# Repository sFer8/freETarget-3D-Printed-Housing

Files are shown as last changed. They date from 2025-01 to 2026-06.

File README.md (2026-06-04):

# freEtarget 3D Printed Housing

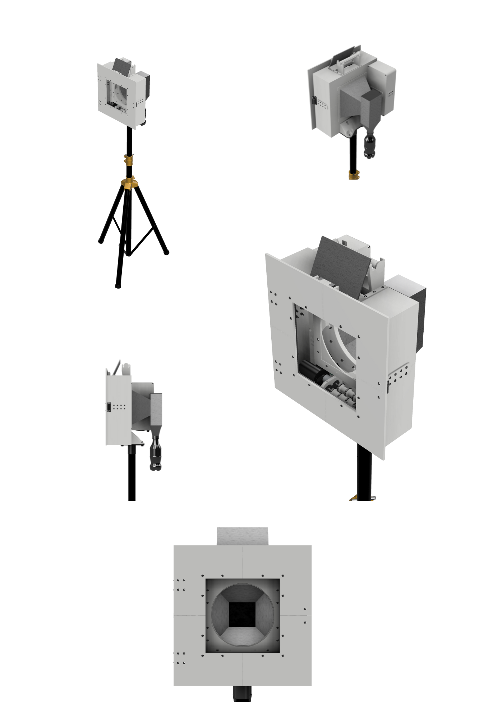
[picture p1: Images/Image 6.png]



## Warning

Some parts of the design have not been tested due to current funding limitations. For instance, my personal target does not include any metal protective components. Additionally, the released designs for the target's face have not been tested due to a shortage of filament. Holes to be printed may require the use of a drill to achieve the appropriate size.

### Paper Target and Witness Paper

The default paper target holder uses a standard 17x17cm target. Both rifle and pistol paper targets should use this size. SUIS style targets have another holder that can be printed however I have not had the chance to test it out. Custom target holders can be requested, but please provide important measurements to assist in their implementation.

For witness paper, a standard roll of black craft paper can be cut to 90mm wide and rolled onto the 3d printed roll holder. When using craft paper, it tends to bend behind the target. As such it will be necessary to put the witness paper in between two target papers as shown in order to have a more favorable result in scoring.

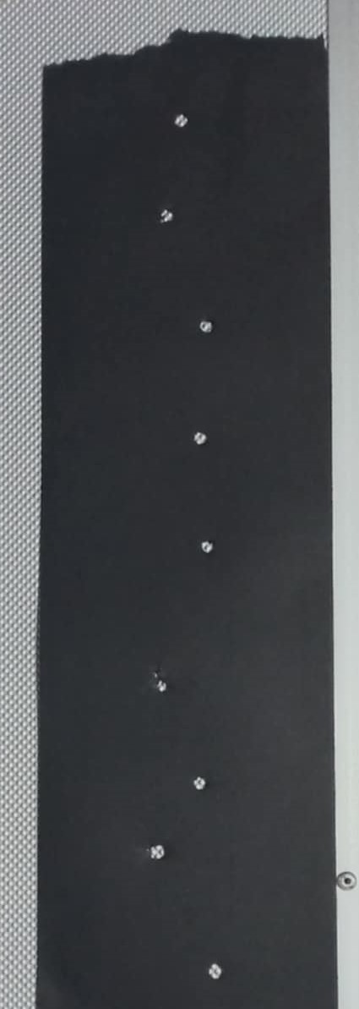
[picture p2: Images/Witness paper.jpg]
Witness paper

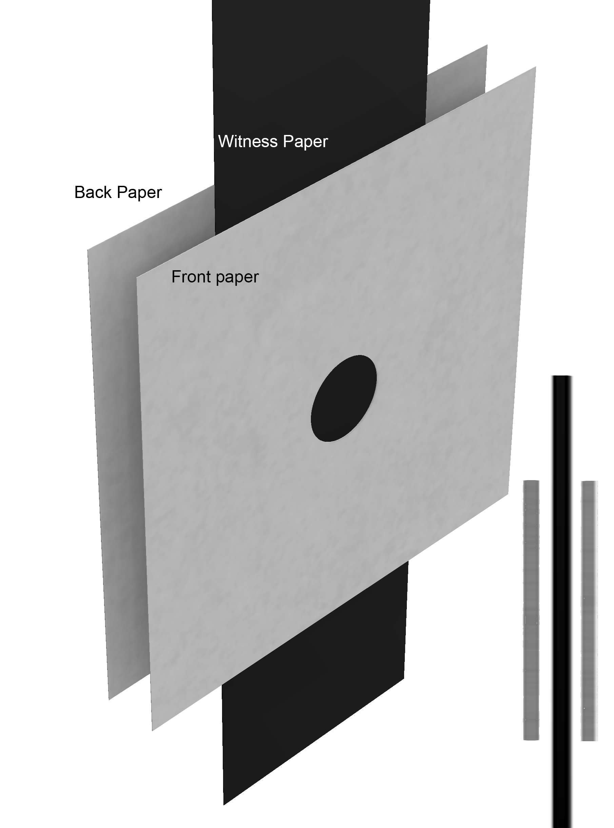
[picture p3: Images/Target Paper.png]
Target Paper

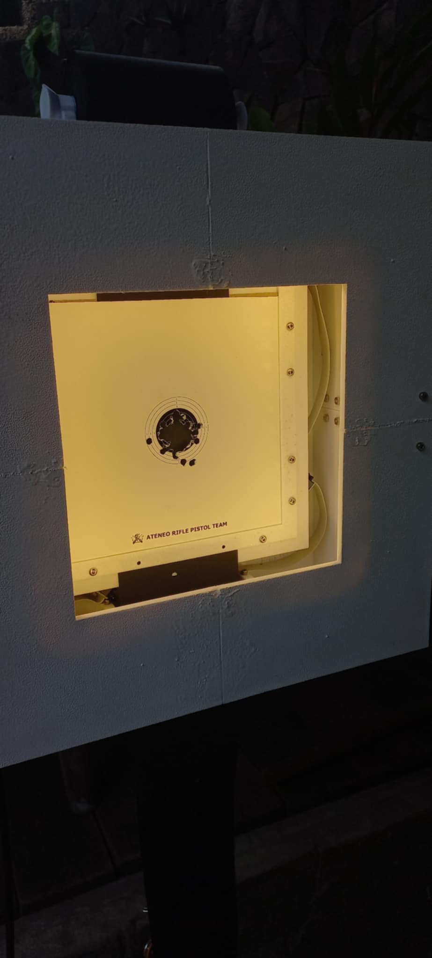
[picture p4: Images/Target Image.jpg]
Target Image


### 3D printed files

The provided 3D printed files should be printed at the recommended settings and with the specified materials. Not following the instructions is at the user's own risk. All models will fit within an Ender 3 build volume. If your 3D printer is capable of printing major sections in one go, you may modify the files to fit your needs.

### Metal Sheets

In the current design, two metal plates are used, excluding the pellet deflector. One plate is found on the witness paper holder, and another is used in the target face option that incorporates metal plates. All steel plates should be 3mm thick to ensure they do not fail.

### Non-3D Printed Components

Below are the similar to what I purchased but from a locally availabe site.

*   [Speaker Stand](https://www.amazon.com/EMART-Adjustable-Speaker-Professional-Structure/dp/B07WVYPBDV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)
    
*   [Fuse](https://www.amazon.com/BOJACK-Values-5X20mm-Black-Holder/dp/B099DW15DW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)
    
*   [90 Degree Concealed Hinge (3 Inch)](https://www.amazon.com/HZyizhihang-10Pcs-3inch-Cabinet-Hinges/dp/B0DXFNSKTV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)
    
*   [Warm White LED Strip](https://www.amazon.com/HitLights-UL-Listed-Premium-2835-16-4-Lighting/dp/B07SWZFMJJ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)

*   [AC cord female](https://www.amazon.com/Panel-Adapter-Connector-Socket-Spring/dp/B081C32LWG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)
    
*   [12v to USB step down](https://www.amazon.com/NOYITO-Adaptive-Current-Charger-Regulators/dp/B07BGSCDB4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)
    
*   [Flexible Coupler (6.35 to 8mm)](https://www.amazon.com/WEIJ-Aluminum-Coupling-Flexible-Connector/dp/B09LC81KJ7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)
    
*   [3 Prong AC power cord](https://www.amazon.com/Standard-Electronics-Computer-Printer-Monitor/dp/B0DPR5GLW1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)
    
*   [DC geared Motor (12V)](https://www.amazon.com/uxcell-ZGB37-3530-High-Speed-Control-Diameter/dp/B0D56VB1SW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)
    
*   [DC Motor Mount](https://www.amazon.com/Mrosnail-37mm-Motor-Mounting-Bracket/dp/B0CRQCGQHF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)
    
*   [Power supply, 12V](https://www.amazon.com/LRS-150W-12-15-24-36-LRS-150-24/dp/B09QM1WMSZ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)
    
*   [23mm Oring](https://www.amazon.com/Sealing-Nitrile-Professional-Plumbing-Connections/dp/B07YJ9Y8V2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)
    
*   M3
    
    *   8mm long (41 pcs)
 
    *   12mm long (6 pcs)
        
    *   16mm long (71 pcs)
        
    *   Nut (83 pcs)
        
*   M4
    
    *   25mm long (4 pcs)
        
    *   Nut (4 pcs)
        
*   M6
    
    *   20mm long (4 pcs)
        
    *   Nut (4 pcs)
*   M8
    
    *   260mm rod (to be cut to 2)
        
    *   Nut (6 pcs)    

Original Designed used a premade pellete trap. Current design recommends using 2 and 3mm steel plates to create a SUIS like pellete trap. This design will make sure pellets are caught and no bounce back occurs. I greatly recommend using this style of trap rather than the original for safety.

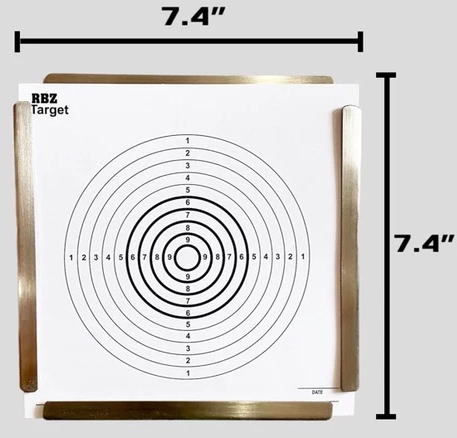
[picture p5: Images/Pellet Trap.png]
Pellet Trap


This is my first github repository. Please feel free to give me comments and tips for the project and my usage of Github. I can be contacted via [Discord](https://discordapp.com/users/247699345250451457). If you feel generous or want to help in funding to make this project better, feel free to drop any small amount [here](paypal.me/sFer8).

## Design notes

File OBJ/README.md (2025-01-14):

# Marged Parts
Due to request, the housing, front cover, electronics box and electronics cover has been merged. It is huge and can only be printed on larger printers with an excruciating long print time.

# Print Settings for 3D printed Parts
Slicing has been done in PrusaSlicer but can be sliced in preferred slicing software. The settings below can be changed at the expense of the user. Recommended Materials are that of PETG and ASA.

## PrusaSlicer Settings

*   Layer Height: 0.3mm
*   Extrusion Width: 0.4mm
*   Infill Percentage: 40%
*   Infill Type: Gyroid
*   Wall Count: 5
*   Solid Top/Bottom Layers: 4

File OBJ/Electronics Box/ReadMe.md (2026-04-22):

## Read Me

Step down converter makes use of a premade design by [Paulvp on Thingiverse](https://www.thingiverse.com/thing:5906278). Please download the top cover for use in the electronics USB buck converter.

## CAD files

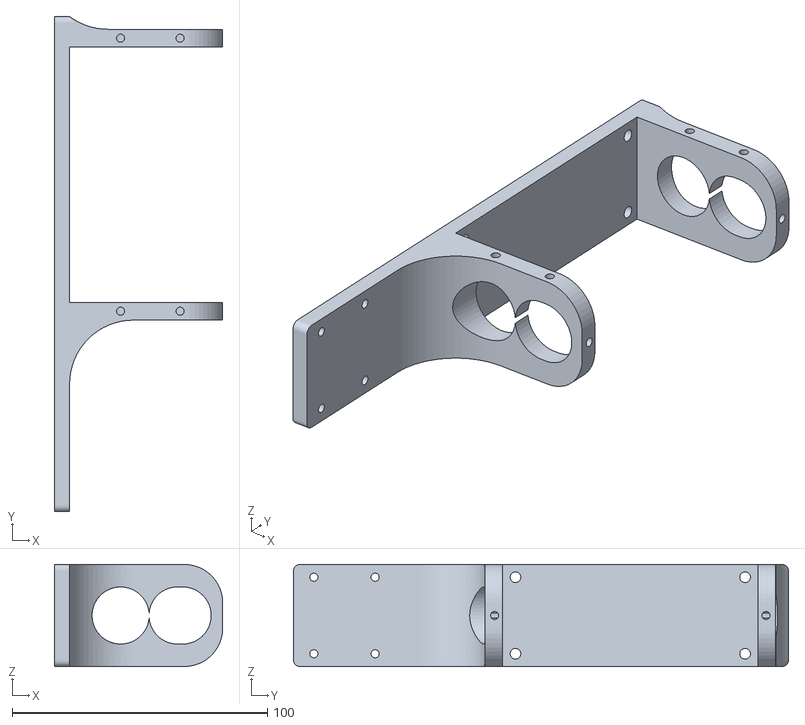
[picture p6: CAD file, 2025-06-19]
OBJ/Paper Drive/Main Mount.obj
66.0 x 194.0 x 40.0

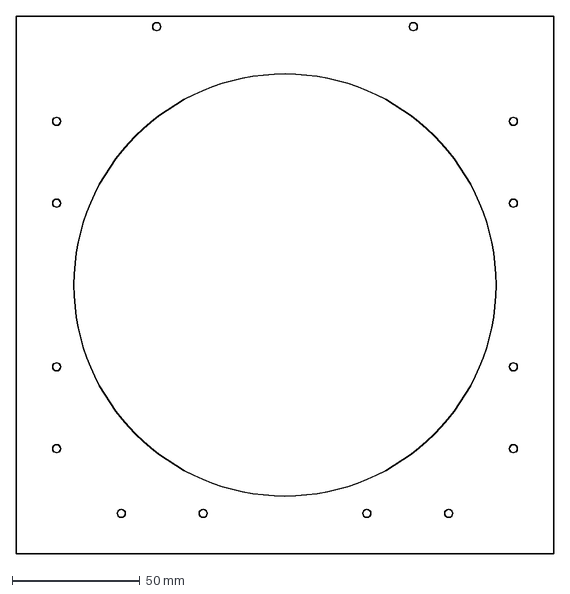
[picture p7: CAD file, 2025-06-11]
DWG/17mm target metal plate.dxf
210.0 x 210.0 mm

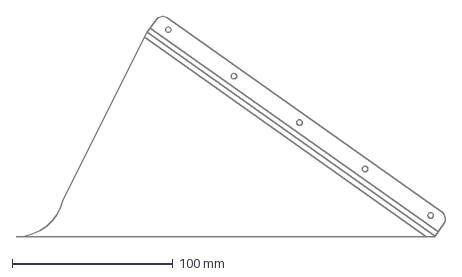
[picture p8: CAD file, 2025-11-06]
DXF/SUIS Style Pellet trap/Bottom.dxf
267.1 x 137.2 mm

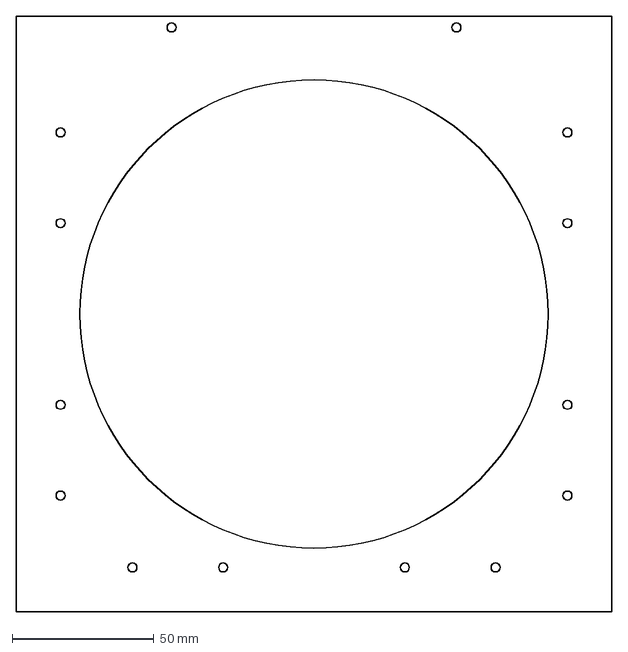
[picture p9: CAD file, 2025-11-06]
DXF/Target Holder Metal Plate.dxf
210.0 x 210.0 mm

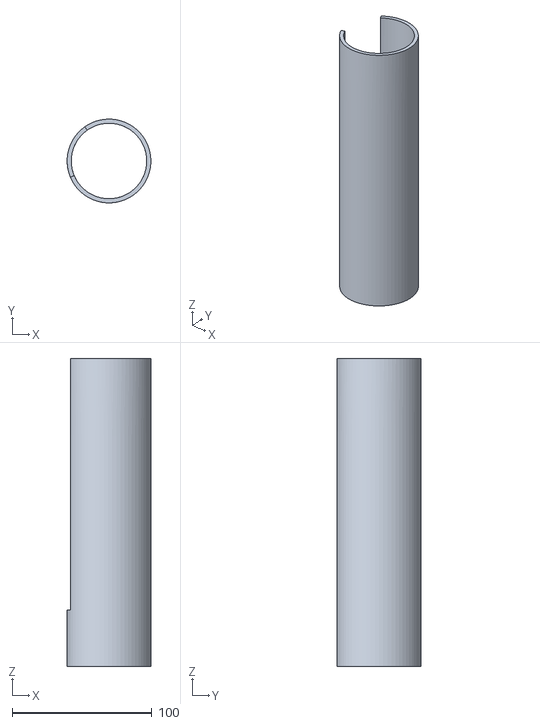
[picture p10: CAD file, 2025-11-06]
OBJ/(Steel plates) SUIS Style Pellet trap/(60mm OD Steel) Pipe.obj
60.0 x 60.0 x 220.5

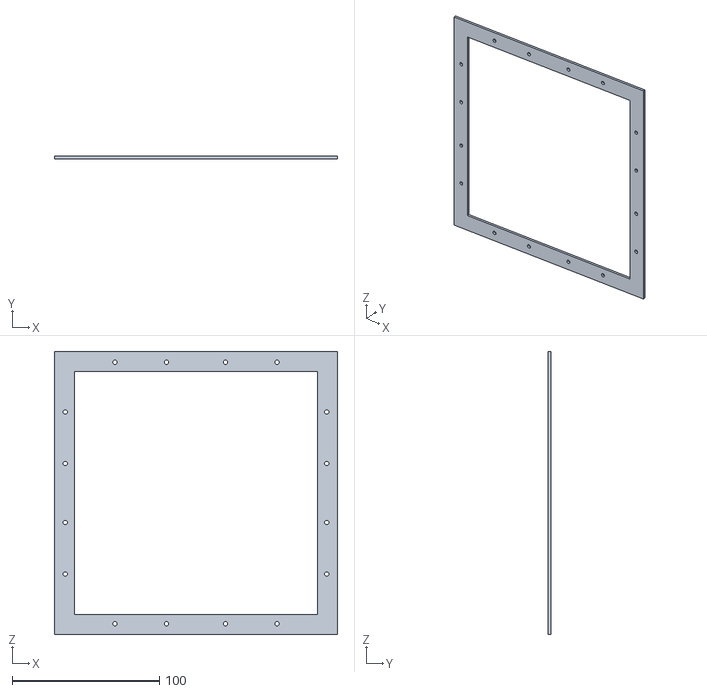
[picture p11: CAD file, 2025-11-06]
OBJ/Drill Guide/Drill Guide.obj
192.0 x 2.00 x 192.0

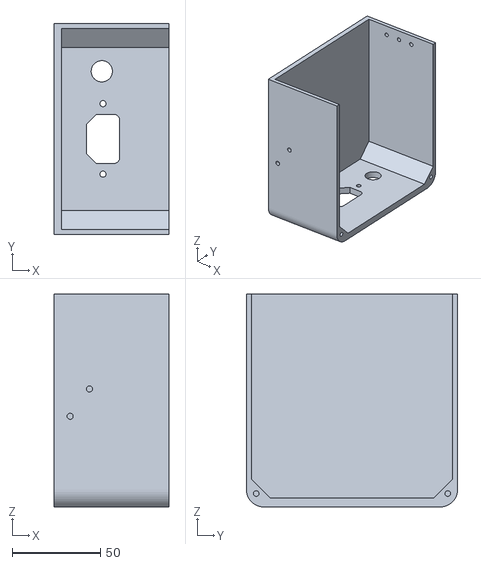
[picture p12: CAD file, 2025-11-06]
OBJ/Electronics Box/Box/Electronics Box Bottom.obj
65.0 x 120.0 x 120.9

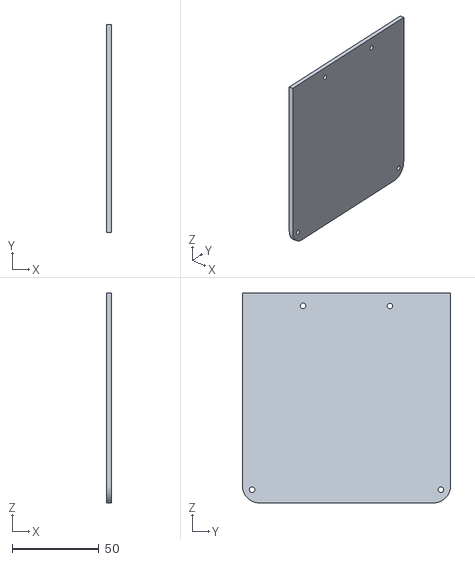
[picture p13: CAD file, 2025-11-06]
OBJ/Electronics Box/Cover/Electronics Cover Bottom.obj
3.00 x 120.0 x 120.9

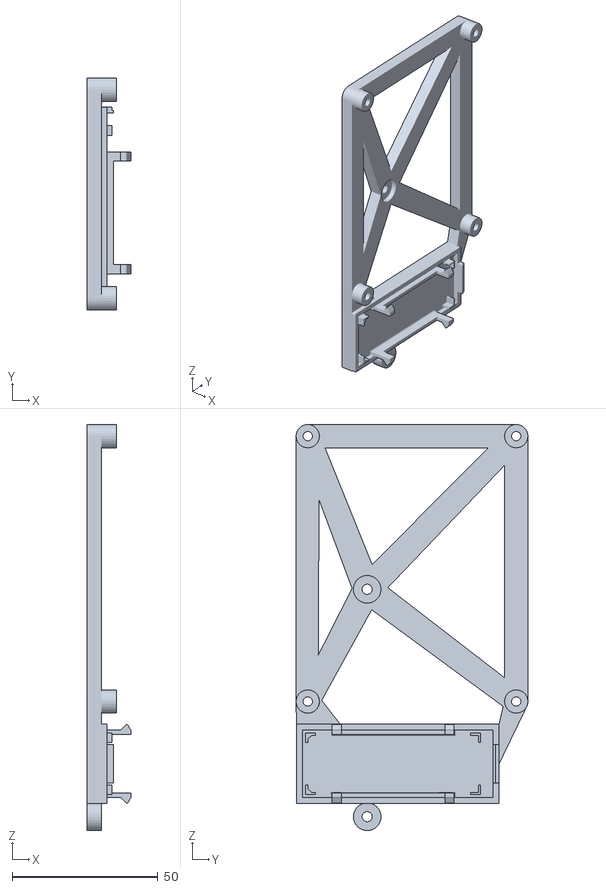
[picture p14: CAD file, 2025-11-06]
OBJ/Electronics Box/Electronics Frame.obj
15.0 x 79.5 x 139.2

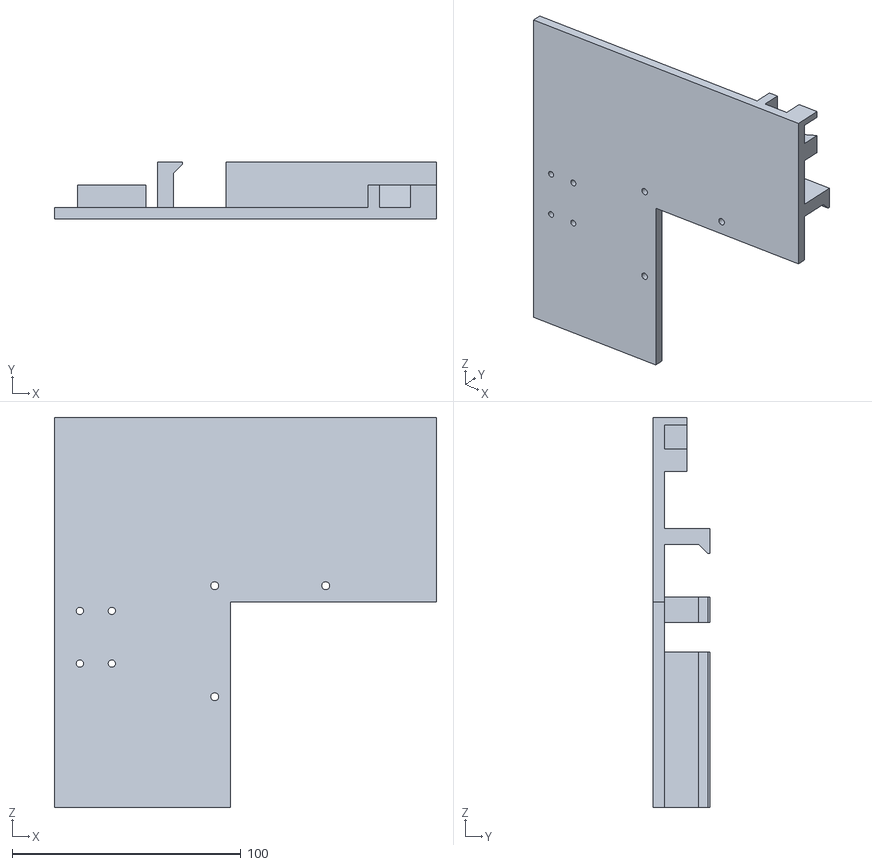
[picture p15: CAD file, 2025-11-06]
OBJ/Housing/Face/Top Left.obj
166.9 x 25.0 x 170.4

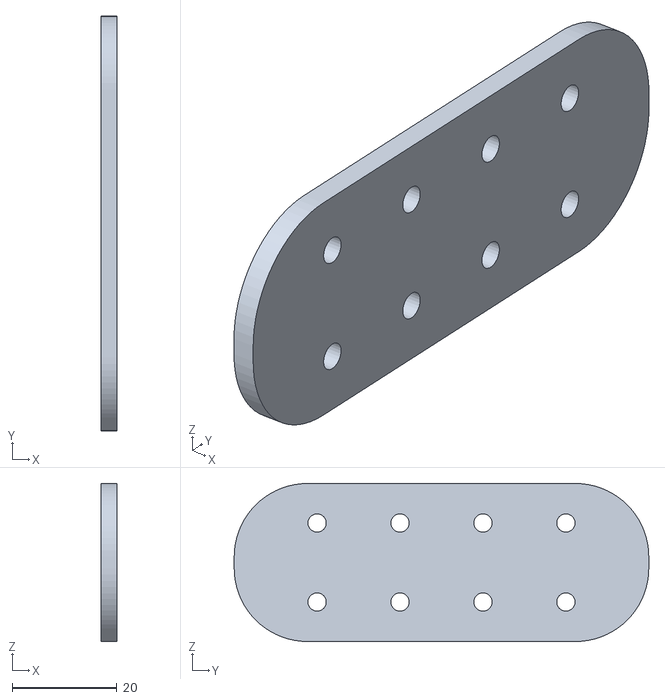
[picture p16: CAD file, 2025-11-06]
OBJ/Joining Plates/Left Joining Plate.obj
3.00 x 79.2 x 30.2

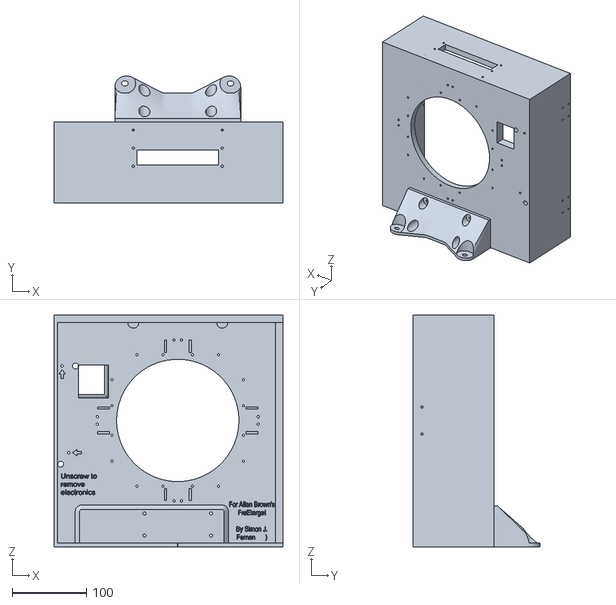
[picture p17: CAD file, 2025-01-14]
OBJ/Merged/Housing.obj
309.0 x 171.2 x 312.5

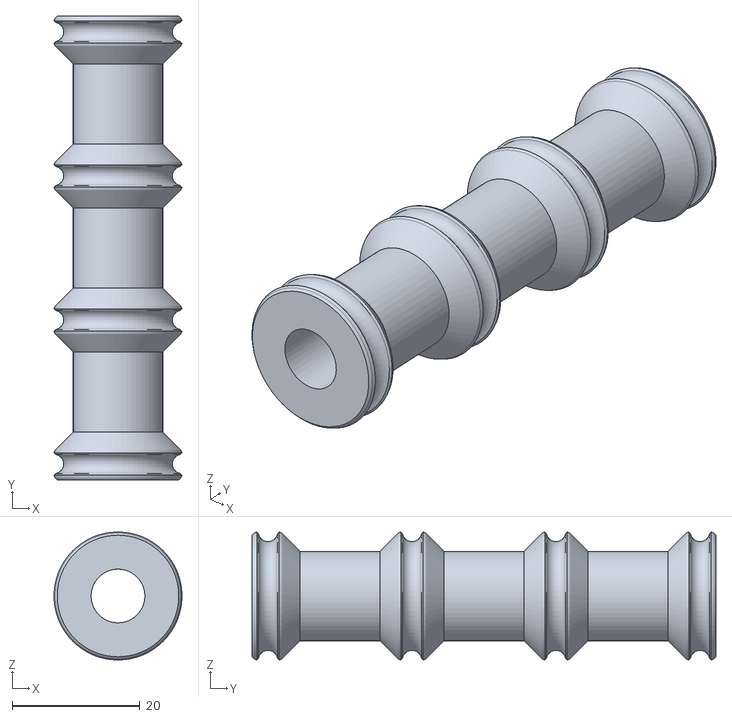
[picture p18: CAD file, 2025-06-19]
OBJ/Paper Drive/Idler Mount.obj
20.0 x 72.5 x 20.0

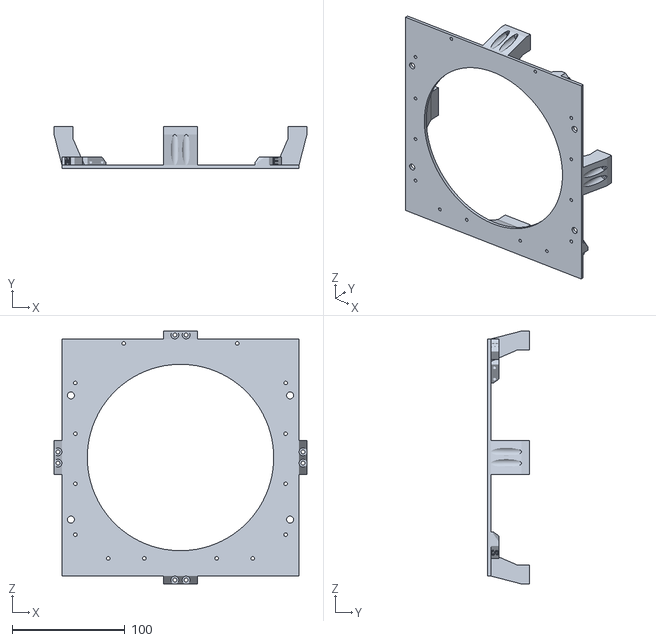
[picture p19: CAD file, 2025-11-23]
OBJ/Target Holder/7 Inch wide target/Target Plate 7 in Target.obj
224.0 x 37.2 x 224.0

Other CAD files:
OBJ/Target Holder/Default (17x17cm target)/(3mm Steel )Metal Plate.obj
OBJ/Target Holder/Default/Target Plate.obj
OBJ/Target Holder/SUIS Target/Sius Metal Plate.obj
OBJ/Target Holder/Witness paper Guide.obj
DWG/Housing Plate.dxf
DWG/SIUS metal plate.dxf
DXF/Housing Metal Plate.dxf
DXF/SUIS Style Pellet trap/Left.dxf
DXF/SUIS Style Pellet trap/Right.dxf
DXF/SUIS Style Pellet trap/Top.dxf
DXF/SUIS Target Holder Metal Plate.dxf
DXF/Witness Paper Deflector.dxf
OBJ/(Steel plates) SUIS Style Pellet trap/(2mm Steel) Bottom.obj
OBJ/(Steel plates) SUIS Style Pellet trap/(2mm Steel) Left.obj
OBJ/(Steel plates) SUIS Style Pellet trap/(2mm Steel) Top.obj
OBJ/(Steel plates) SUIS Style Pellet trap/(3mm Steel) Right.obj
OBJ/(Steel plates) SUIS Style Pellet trap/Bottle Adapter.obj
OBJ/Electronics Box/Box/Electronics Box Top.obj
OBJ/Electronics Box/Cover/Electronics Cover Top.obj
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

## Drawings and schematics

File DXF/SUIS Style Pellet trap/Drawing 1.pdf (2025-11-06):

50 | 50 | 50 | 50 | Ø3.5 ¹⁴.61 | 14.61

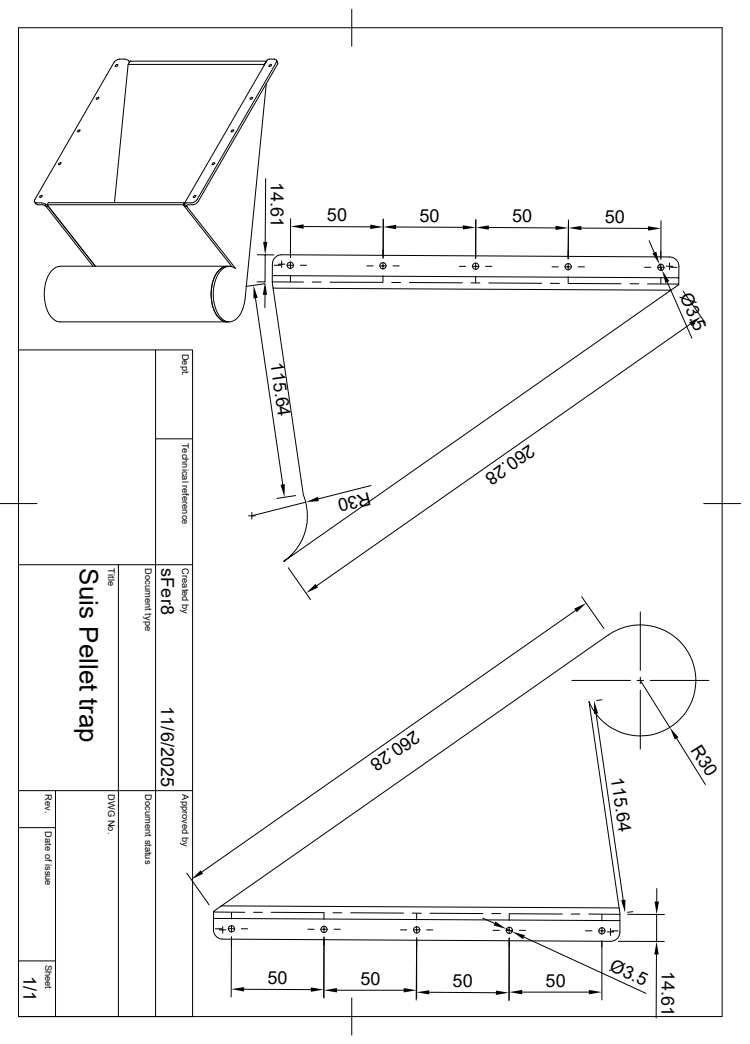
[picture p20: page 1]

Dept. Technical reference Created by Approved by Title DWG No. Document type Document status Rev. Date of issue Sheet 11/6/2025 1/1 Suis Pellet trap sFer8

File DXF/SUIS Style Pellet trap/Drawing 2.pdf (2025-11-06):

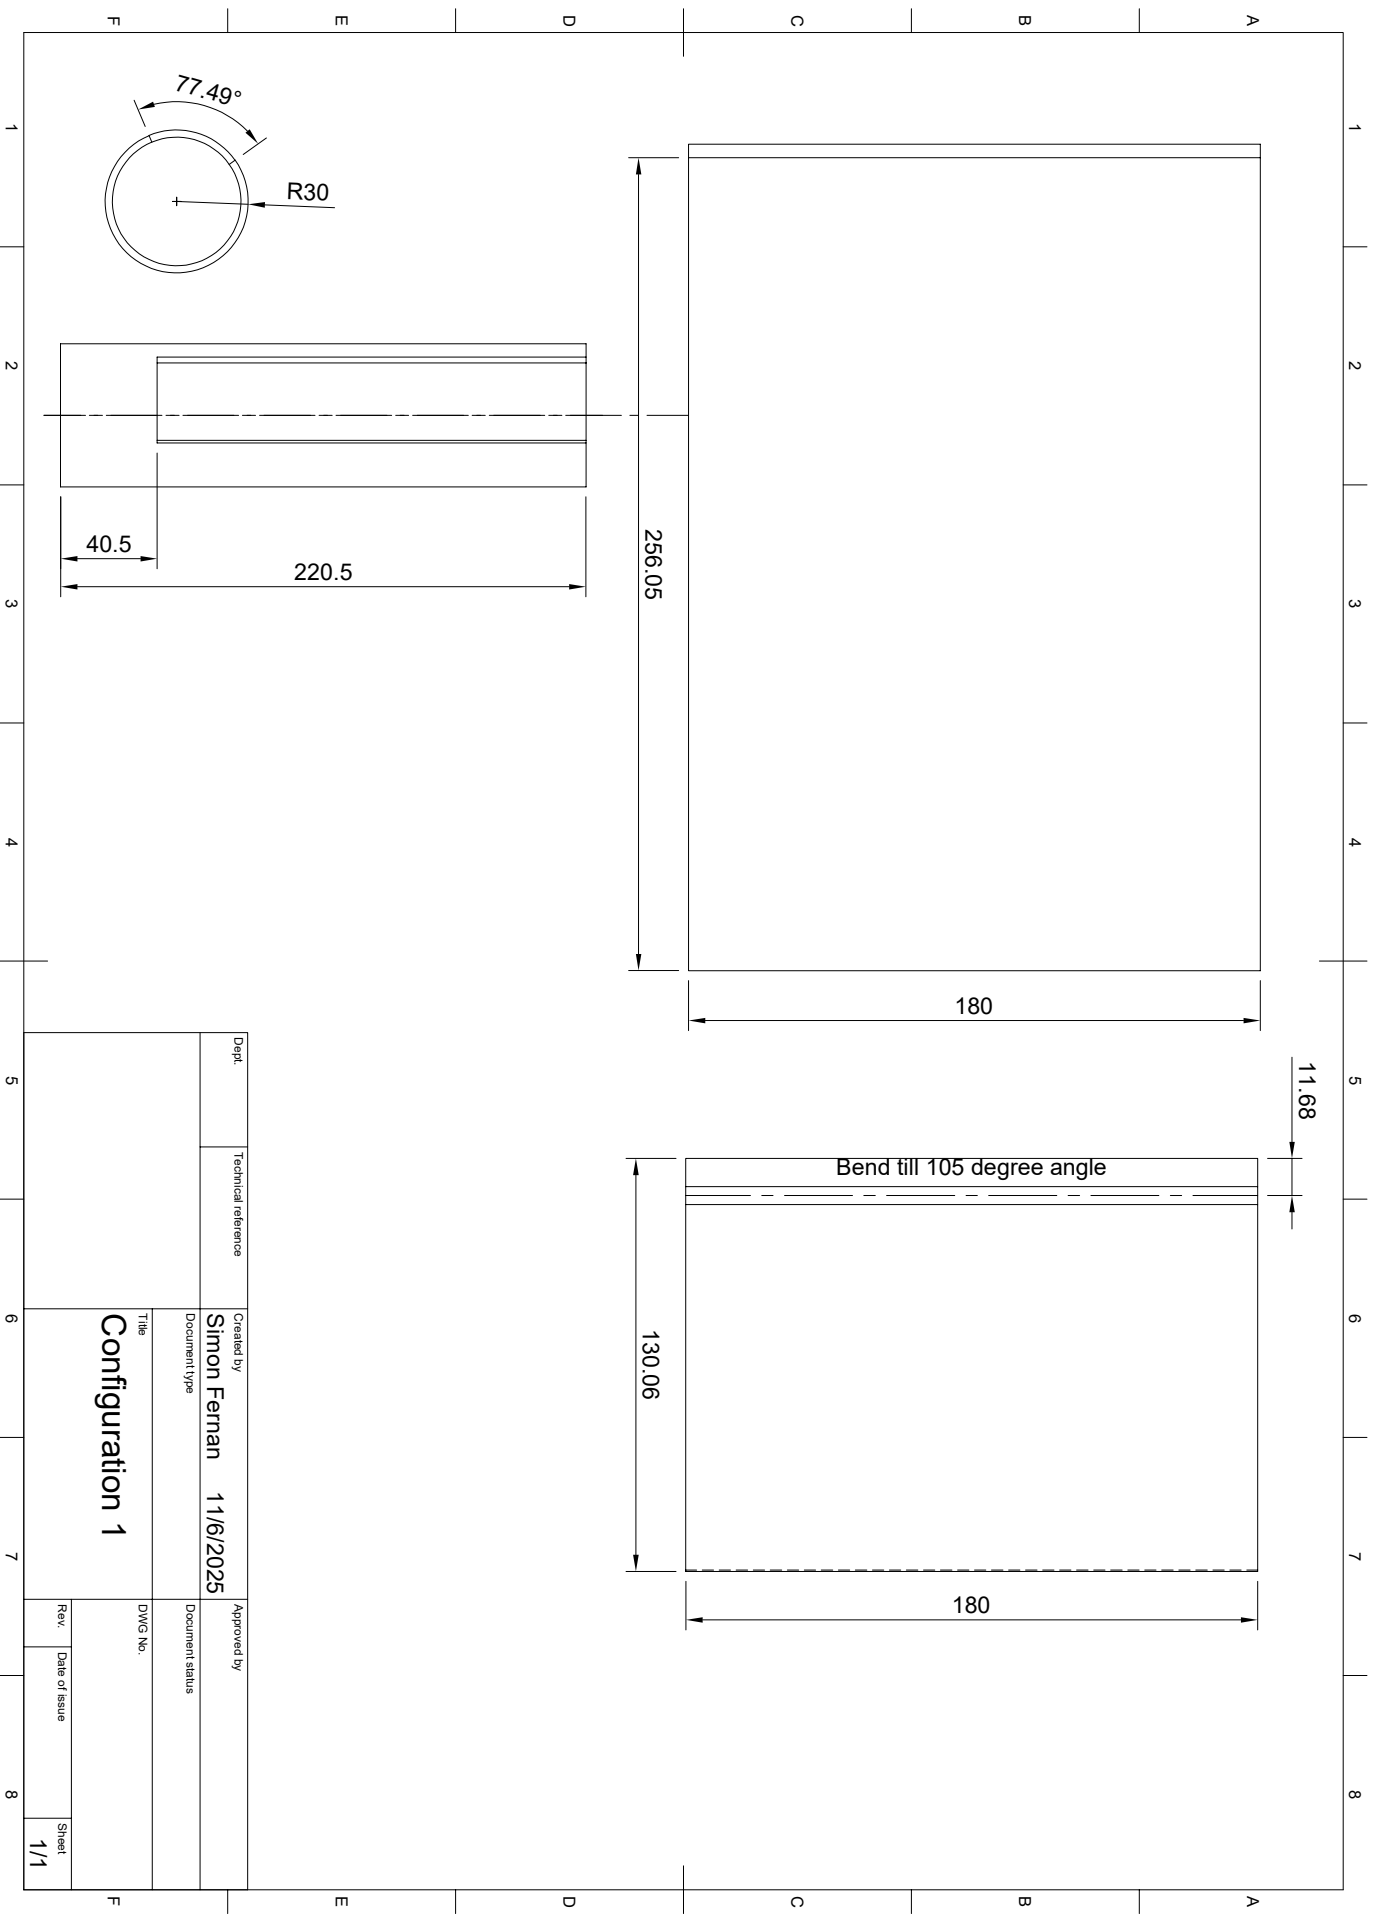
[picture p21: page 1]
180 ¹³⁰.06

1 A 2 3 4 5 6 7 8 1 2 3 4 5 6 7 8 FEDCB FEDCBA Dept. Technical reference Created by Approved by Title DWG No. Document type Document status Rev. Date of issue Sheet 11/6/2025 1/1 Configuration 1 Simon Fernan 256.05

Bend till 105 degree angle

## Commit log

2025-01-06 Added CAD files
2025-01-06 Added STL Files
    [(3mm Steell) Steel Housing plate.obj, (3mm Steell) Steel Pellet Deflector.obj, Bottom Left.obj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]
2025-01-08 Added SUIS target holder
    [SUIS Knob 1.obj, SUIS Knob 2.obj, SUIS Target Plate.obj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]
2025-01-10 Updated README.md
    Added Motor drive hardware to the list
2025-01-14 Added merged models
    Added merged models for larger print volumes
    [Electronics Box Bottom.obj, Electronics Cover Bottom.obj, Face Plate.obj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]
2025-06-11 Added new CAD and DWG files
    Added the DWG files to be cut for the metal plates. Updated the CAD with a new pellet trap. Modified current housing to use more M3 nuts
    [17mm target metal plate.dxf, Housing Plate.dxf, SIUS metal plate.dxf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]
2025-06-19 Added the missing paper drive assembly
    [Idler Mount.obj, Main Mount.obj]
2025-11-06 Updated print files
    Updated OBJ files to match latest CAD files
    [(2mm Steel) Bottom.obj, (2mm Steel) Left.obj, (2mm Steel) Top.obj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]
2025-11-06 Renamed DWG to DXF and updated files
    [Bottom.dxf, Housing Metal Plate.dxf, Left.dxf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]
2025-11-06 Renamed File
    [(2mm Steel) Bottom.obj, (2mm Steel) Left.obj, (2mm Steel) Top.obj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]
2025-11-08 Updated hinge link and added one for AC cord female connector
2025-11-23 Added target holder for 7 inch wide target
    [Metal Plate for 7in Target.dxf, Targe Holder 7 in Target.obj, Target Plate 7 in Target.obj]
2026-04-22 Added buck converter cover download link
2026-06-02 Update power supply entry in README
2026-06-04 Update DC geared Motor link to include voltage
